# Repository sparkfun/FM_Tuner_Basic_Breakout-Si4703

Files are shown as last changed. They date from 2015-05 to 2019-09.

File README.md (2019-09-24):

SparkFun FM Tuner Basic Breakout - Si4703
========================================

SparkFun FM Tuner Basic Breakout - Si4703

[*SparkFun FM Tuner Basic Breakout - Si4703 (BOB-11083)*](https://www.sparkfun.com/products/11083)

This breakout for the Silicon Laboratories Si4703 FM tuner chip is a little more stripped down than our FM Tuner Evaluation Board. If your project already has an amp and just needs a full-featured FM tuner, this is the board for you. 

_Note: If you are using a different microcontroller that is 5V, you will need to connect to the [respective I2C pins](https://www.arduino.cc/en/reference/wire), and match the [logic levels](https://learn.sparkfun.com/tutorials/logic-levels). Make sure to add the [4-channel bi-directional logic level converter](https://www.sparkfun.com/products/12009) between SDIO, SCLK, RST, and GPIO2._

Repository Contents
-------------------

* **/Firmware** - Example code 
* **/Hardware** - Eagle design files (.brd, .sch)
* **/Libraries** - Libraries for use with the <PRODUCT NAME>
* **/Production** - Production panel files (.brd)

Documentation
--------------
* **[Library](https://github.com/sparkfun/SparkFun_Si4703_Arduino_Library)** - Arduino library for the Si4703.
* **[SparkFun Fritzing repo](https://github.com/sparkfun/Fritzing_Parts)** - Fritzing diagrams for SparkFun products.
* **[SparkFun 3D Model repo](https://github.com/sparkfun/3D_Models)** - 3D models of SparkFun products. 

License Information
-------------------
This product is _**open source**_! 

The **hardware** is released under [Creative Commons ShareAlike 4.0 International](https://creativecommons.org/licenses/by-sa/4.0/).

The **code** is beerware; if you see me (or any other SparkFun employee) at the local, and you've found our code helpful, please buy us a round!

Please use, reuse, and modify these files as you see fit. Please maintain attribution to SparkFun Electronics and release anything derivative under the same license.

Distributed as-is; no warranty is given.

- Your friends at SparkFun.

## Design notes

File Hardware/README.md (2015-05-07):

SparkFun <PRODUCT NAME> Design Files
=====================================

The .sch and .brd files hare are Eagle CAD schematic and PCB design files from SparkFun Electronics.
A freeware version of Eagle can be found [here](http://www.cadsoftusa.com/download-eagle/freeware/). 

License
---------
This product is open source! 
The hardware is released under [Creative Commons ShareAlike 4.0 International](https://creativecommons.org/licenses/by-sa/4.0/).

Please use, reuse, and modify these files as you see fit. Please maintain attribution to SparkFun Electronics and release anything derivative under the same license.

Distributed as-is; no warranty is given.

- Your friends at SparkFun.

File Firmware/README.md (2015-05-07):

SparkFun Si4703 Firmware
===================================

* **SparkFunSi4703Demo** - Arduino demo sketch. No library required.

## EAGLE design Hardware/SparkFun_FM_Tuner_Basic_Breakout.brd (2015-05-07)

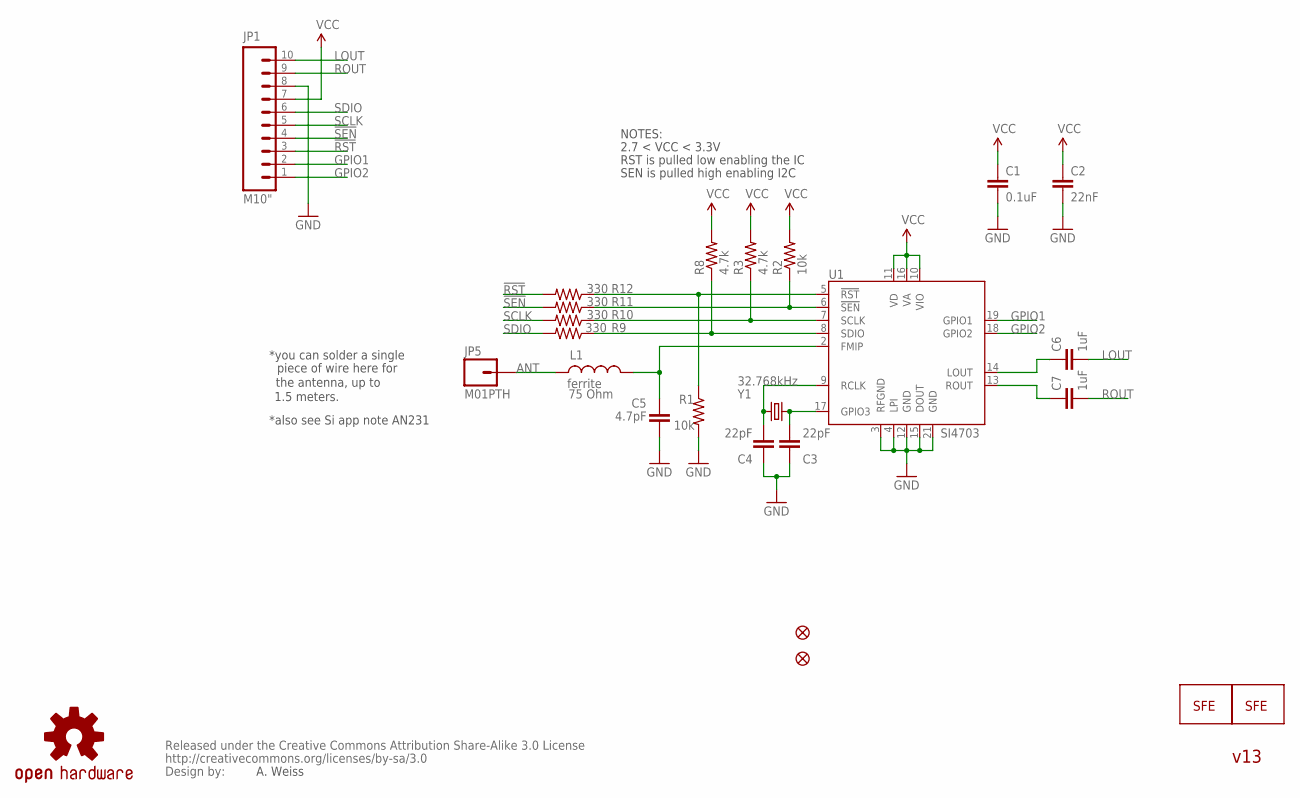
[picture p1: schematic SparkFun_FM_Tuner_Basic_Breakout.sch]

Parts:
C1: 0.1uF; 0402-CAP
C2: 22nF; 0402-CAP
C3, C4: 22pF; 0402-CAP
C5: 4.7pF; 0402-CAP
C6, C7: 1uF; 0402-CAP
JP1: M10"; 1X10
JP2: LOGO-SFENW2; SFE-NEW-WEB
JP3: LOGO-SFESK; SFE-LOGO-FLAME
JP4, JP6: FIDUCIALUFIDUCIAL; MICRO-FIDUCIAL
JP5: M01PTH; 1X01
L1: ferrite; C0402
R1, R2: 10k; 0402-RES
R3, R8: 4.7k; 0402-RES
R9, R10, R11, R12: 330; 0402-RES
U1: SI4703; SPARKFUN_SI470X
U$1: CREATIVE_COMMONS
U$3: OSHW-LOGOS; OSHW-LOGO-S
Y1: 32.768kHz; CRYSTAL-32KHZ-SMD

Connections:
3.3V: C1.1, C2.1, JP1.7, R2.2, R3.2, R8.2, U1.10 (VIO), U1.11 (VD), U1.16 (VA)
!RST: JP1.3, R12.2
!RST-L: R1.1, R12.1, U1.5 (!RST)
!SEN: JP1.4, R11.2
!SEN-L: R2.1, R11.1, U1.6 (!SEN)
ANT: JP5.1, L1.1
GND: C1.2, C2.2, C3.1, C4.1, C5.2, JP1.8, R1.2, U1.3 (RFGND), U1.4 (LPI), U1.12 (GND), U1.15 (DOUT), U1.21 (GND)
GPIO1: JP1.2, U1.19 (GPIO1)
GPIO2: JP1.1, U1.18 (GPIO2)
LOUT: C6.2, JP1.10
unnamed: C4.2, U1.9 (RCLK), Y1.X2 (2)
unnamed: C3.2, U1.17 (GPIO3), Y1.X1 (1)
unnamed: C5.1, L1.2, U1.2 (FMIP)
unnamed: C6.1, U1.14 (LOUT)
unnamed: C7.1, U1.13 (ROUT)
ROUT: C7.2, JP1.9
SCLK: JP1.5, R10.2
SCLK-L: R3.1, R10.1, U1.7 (SCLK)
SDIO: JP1.6, R9.2
SDIO-L: R8.1, R9.1, U1.8 (SDIO)

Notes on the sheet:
SEN is pulled high enabling I2C
RST is pulled low enabling the IC
A. Weiss
2.7 < VCC < 3.3V
NOTES:
*you can solder a single
piece of wire here for
the antenna, up to
1.5 meters.
*also see Si app note AN231
v13

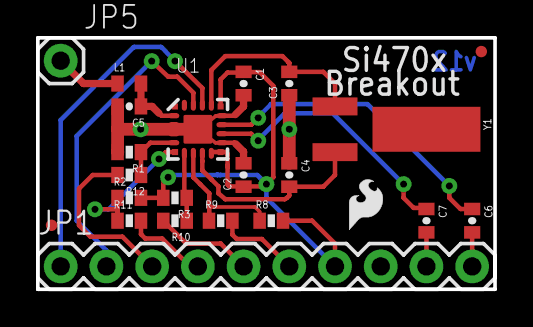
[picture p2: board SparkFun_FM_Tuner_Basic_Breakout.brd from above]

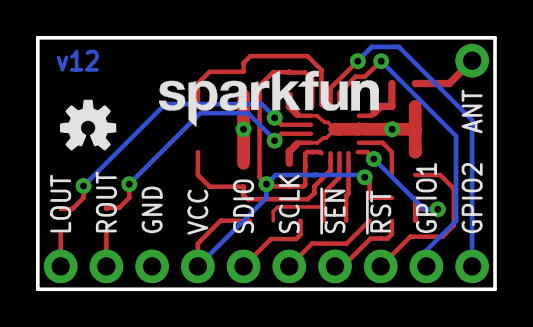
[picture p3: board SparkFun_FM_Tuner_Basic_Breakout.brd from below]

Board: 2 copper layers, 25.4 x 14.0 mm, 26 parts (2 on the bottom side), 20 nets.

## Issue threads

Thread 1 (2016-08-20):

No need to wait for data after Wire.requestFrom()

Koepel, 2016-08-20:
In one place in SparkFunSi4703Demo.ino, there is a while-loop after the Wire.requestFrom() call. That while-loop is not needed.

When the Wire.requestFrom() function returns, the I2C transaction has completely finished and the received data is in the receive buffer in the Wire library. The Wire.read() only reads data from that buffer.

When there was a I2C bus error or I2C collision, there would be less bytes received, and that while-loop would halt the sketch.

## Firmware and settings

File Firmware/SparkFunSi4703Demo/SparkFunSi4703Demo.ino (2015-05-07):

/*
 1-6-2011
 Spark Fun Electronics 2011
 Nathan Seidle
 
 This code is public domain but you buy me a beer if you use this and we meet someday (Beerware license).
 
 To use this code, connect the following 5 wires:
 Arduino : Si470x board
 3.3V : VCC
 GND : GND
 A5 : SCLK
 A4 : SDIO
 D2 : RST
 A0 : Trimpot (optional)
 
 Look for serial output at 57600bps.
 
 The Si4703 ACKs the first byte, and NACKs the 2nd byte of a read.
 
 1/18 - after much hacking, I suggest NEVER write to a register without first reading the contents of a chip.
 ie, don't updateRegisters without first readRegisters.
 
 If anyone manages to get this datasheet downloaded
 http://wenku.baidu.com/view/d6f0e6ee5ef7ba0d4a733b61.html
 Please let us know. It seem to be the latest version of the programming guide. It had a change on page 12 (write 0x8100 to 0x07)
 that allowed me to get the chip working..
 
 Also, if you happen to find "AN243: Using RDS/RBDS with the Si4701/03", please share. I love it when companies refer to
 documents that don't exist.
 
 1/20 - Picking up FM stations from a plane flying over Portugal! Sweet! 93.9MHz sounds a little soft for my tastes,s but
 it's in Porteguese.
 
 ToDo:
 Display current status (from 0x0A) - done 1/20/11
 Add RDS decoding - works, sort of
 Volume Up/Down - done 1/20/11
 Mute toggle - done 1/20/11
 Tune Up/Down - done 1/20/11
 Read current channel (0xB0) - done 1/20/11
 Setup for Europe - done 1/20/11
 Seek up/down - done 1/25/11
 
 The Si4703 breakout does work with line out into a stereo or other amplifier. Be sure to test with different length 3.5mm
 cables. Too short of a cable may degrade reception.
 */

#include <Wire.h>

int STATUS_LED = 13;
int resetPin = 2;
int SDIO = A4; //SDA/A4 on Arduino
int SCLK = A5; //SCL/A5 on Arduino
char printBuffer[50];
uint16_t si4703_registers[16]; //There are 16 registers, each 16 bits large

#define FAIL  0
#define SUCCESS  1

#define SI4703 0x10 //0b._001.0000 = I2C address of Si4703 - note that the Wire function assumes non-left-shifted I2C address, not 0b.0010.000W
#define I2C_FAIL_MAX  10 //This is the number of attempts we will try to contact the device before erroring out

//#define IN_EUROPE //Use this define to setup European FM reception. I wuz there for a day during testing (TEI 2011).

#define SEEK_DOWN  0 //Direction used for seeking. Default is down
#define SEEK_UP  1

//Define the register names
#define DEVICEID 0x00
#define CHIPID  0x01
#define POWERCFG  0x02
#define CHANNEL  0x03
#define SYSCONFIG1  0x04
#define SYSCONFIG2  0x05
#define STATUSRSSI  0x0A
#define READCHAN  0x0B
#define RDSA  0x0C
#define RDSB  0x0D
#define RDSC  0x0E
#define RDSD  0x0F

//Register 0x02 - POWERCFG
#define SMUTE  15
#define DMUTE  14
#define SKMODE  10
#define SEEKUP  9
#define SEEK  8

//Register 0x03 - CHANNEL
#define TUNE  15

//Register 0x04 - SYSCONFIG1
#define RDS  12
#define DE  11

//Register 0x05 - SYSCONFIG2
#define SPACE1  5
#define SPACE0  4

//Register 0x0A - STATUSRSSI
#define RDSR  15
#define STC  14
#define SFBL  13
#define AFCRL  12
#define RDSS  11
#define STEREO  8

void setup() {                
  pinMode(13, OUTPUT);
  pinMode(A0, INPUT); //Optional trimpot for analog station control

  Serial.begin(57600);
  Serial.println();

  si4703_init(); //Init the Si4703 - we need to toggle SDIO before Wire.begin takes over.

}

void loop() {
  char option;
  char vol = 15;
  int currentChannel = 973; //Default the unit to a known good local radio station

  gotoChannel(currentChannel);

  while(1) {
    Serial.println();
    Serial.println("Si4703 Configuration");

    currentChannel = readChannel();
    sprintf(printBuffer, "Current station: %02d.%01dMHz", currentChannel / 10, currentChannel % 10);
    Serial.println(printBuffer);

#ifdef IN_EUROPE
    Serial.println("Configured for European Radio");
#endif

    Serial.println("1) Tune to 97.3");
    Serial.println("2) Mute On/Off");
    Serial.println("3) Display status");
    Serial.println("4) Seek up");
    Serial.println("5) Seek down");
    Serial.println("6) Poll for RDS");
    Serial.println("r) Print registers");
    Serial.println("8) Turn GPIO1 High");
    Serial.println("9) Turn GPIO1 Low");
    Serial.println("v) Volume");
    Serial.println("w) Tune up");
    Serial.println("s) Tune down");
    Serial.print(": ");

    while (!Serial.available());
    option = Serial.read();

    if(option == '1')  {
      Serial.println("Tune to 97.3");
      currentChannel = 973;
      //currentChannel = 1023;
      gotoChannel(currentChannel);
    }
    else if(option == '2') {
      Serial.println("Mute toggle");
      si4703_readRegisters();
      si4703_registers[POWERCFG] ^= (1<<DMUTE); //Toggle Mute bit
      si4703_updateRegisters();
    }
    else if(option == '3') {
      si4703_readRegisters();

      Serial.println();
      Serial.println("Radio Status:");

      if(si4703_registers[STATUSRSSI] & (1<<RDSR)){
        Serial.print(" (RDS Available)");

        byte blockerrors = (si4703_registers[STATUSRSSI] & 0x0600) >> 9; //Mask in BLERA
        if(blockerrors == 0) Serial.print (" (No RDS errors)");
        if(blockerrors == 1) Serial.print (" (1-2 RDS errors)");
        if(blockerrors == 2) Serial.print (" (3-5 RDS errors)");
        if(blockerrors == 3) Serial.print (" (6+ RDS errors)");
      }
      else
        Serial.print(" (No RDS)");

      if(si4703_registers[STATUSRSSI] & (1<<STC)) Serial.print(" (Tune Complete)");
      if(si4703_registers[STATUSRSSI] & (1<<SFBL)) 
        Serial.print(" (Seek Fail)");
      else
        Serial.print(" (Seek Successful!)");
      if(si4703_registers[STATUSRSSI] & (1<<AFCRL)) Serial.print(" (AFC/Invalid Channel)");
      if(si4703_registers[STATUSRSSI] & (1<<RDSS)) Serial.print(" (RDS Synch)");

      if(si4703_registers[STATUSRSSI] & (1<<STEREO)) 
        Serial.print(" (Stereo!)");
      else
        Serial.print(" (Mono)");

      byte rssi = si4703_registers[STATUSRSSI] & 0x00FF; //Mask in RSSI
      Serial.print(" (RSSI=");
      Serial.print(rssi, DEC);
      Serial.println(" of 75)");
    }
    else if(option == '4') {
      seek(SEEK_UP);
    }
    else if(option == '5') {
      seek(SEEK_DOWN);
    }
    else if(option == '6') {
      Serial.println("Poll RDS - x to exit");
      while(1) {
        if(Serial.available() > 0)
          if(Serial.read() == 'x') break;

        si4703_readRegisters();
        if(si4703_registers[STATUSRSSI] & (1<<RDSR)){
          Serial.println("We have RDS!");
          byte Ah, Al, Bh, Bl, Ch, Cl, Dh, Dl;
          Ah = (si4703_registers[RDSA] & 0xFF00) >> 8;
          Al = (si4703_registers[RDSA] & 0x00FF);

          Bh = (si4703_registers[RDSB] & 0xFF00) >> 8;
          Bl = (si4703_registers[RDSB] & 0x00FF);

          Ch = (si4703_registers[RDSC] & 0xFF00) >> 8;
          Cl = (si4703_registers[RDSC] & 0x00FF);

          Dh = (si4703_registers[RDSD] & 0xFF00) >> 8;
          Dl = (si4703_registers[RDSD] & 0x00FF);

          Serial.print("RDS: ");
          Serial.print(Ah);
          Serial.print(Al);
          Serial.print(Bh);
          Serial.print(Bl);
          Serial.print(Ch);
          Serial.print(Cl);
          Serial.print(Dh);
          Serial.print(Dl);
          Serial.println(" !");

          delay(40); //Wait for the RDS bit to clear
        }
        else {
          Serial.println("No RDS");
          delay(30); //From AN230, using the polling method 40ms should be sufficient amount of time between checks
        }
        //delay(500);
      }
    }
    else if(option == '8') {
      Serial.println("GPIO1 High");
      si4703_registers[SYSCONFIG1] |= (1<<1) | (1<<0);
      si4703_updateRegisters();
    }
    else if(option == '9') {
      Serial.println("GPIO1 Low");
      si4703_registers[SYSCONFIG1] &= ~(1<<0);
      si4703_updateRegisters();
    }
    else if(option == 'r') {
      Serial.println("Print registers");
      si4703_printRegisters();
    }
    else if(option == 't') {
      Serial.println("Trim pot tuning");
      while(1) {
        if(Serial.available())
          if(Serial.read() == 'x') break;

        int trimpot = 0;
        for(int x = 0 ; x < 16 ; x++)
          trimpot += analogRead(A0);
        trimpot /= 16; //Take average of trimpot reading

        Serial.print("Trim: ");
        Serial.print(trimpot);
        trimpot = map(trimpot, 0, 1023, 875, 1079); //Convert the trimpot value to a valid station
        Serial.print(" station: ");
        Serial.println(trimpot);
        if(trimpot != currentChannel) {
          currentChannel = trimpot;
          gotoChannel(currentChannel);
        }

        delay(100);
      }
    }
    else if(option == 'v') {

      byte current_vol;

      Serial.println();
      Serial.println("Volume:");
      Serial.println("+) Up");
      Serial.println("-) Down");
      Serial.println("x) Exit");
      while(1){
        if(Serial.available()){
          option = Serial.read();
          if(option == '+') {
            si4703_readRegisters(); //Read the current register set
            current_vol = si4703_registers[SYSCONFIG2] & 0x000F; //Read the current volume level
            if(current_vol < 16) current_vol++; //Limit max volume to 0x000F
            si4703_registers[SYSCONFIG2] &= 0xFFF0; //Clear volume bits
            si4703_registers[SYSCONFIG2] |= current_vol; //Set new volume
            si4703_updateRegisters(); //Update
            Serial.print("Volume: ");
            Serial.println(current_vol, DEC);
          }
          if(option == '-') {
            si4703_readRegisters(); //Read the current register set
            current_vol = si4703_registers[SYSCONFIG2] & 0x000F; //Read the current volume level
            if(current_vol > 0) current_vol--; //You can't go lower than zero
            si4703_registers[SYSCONFIG2] &= 0xFFF0; //Clear volume bits
            si4703_registers[SYSCONFIG2] |= current_vol; //Set new volume
            si4703_updateRegisters(); //Update
            Serial.print("Volume: ");
            Serial.println(current_vol, DEC);
          }
          else if(option == 'x') break;
        }
      }
    }

    else if(option == 'w') {
      currentChannel = readChannel();
#ifdef IN_EUROPE
      currentChannel += 1; //Increase channel by 100kHz
#else
      currentChannel += 2; //Increase channel by 200kHz
#endif
      gotoChannel(currentChannel);
    }
    else if(option == 's') {
      currentChannel = readChannel();
#ifdef IN_EUROPE
      currentChannel -= 1; //Decreage channel by 100kHz
#else
      currentChannel -= 2; //Decrease channel by 200kHz
#endif
      gotoChannel(currentChannel);
    }
    else {
      Serial.print("Choice = ");
      Serial.println(option);
    }
  }
}

//Given a channel, tune to it
//Channel is in MHz, so 973 will tune to 97.3MHz
//Note: gotoChannel will go to illegal channels (ie, greater than 110MHz)
//It's left to the user to limit these if necessary
//Actually, during testing the Si4703 seems to be internally limiting it at 87.5. Neat.
void gotoChannel(int newChannel){
  //Freq(MHz) = 0.200(in USA) * Channel + 87.5MHz
  //97.3 = 0.2 * Chan + 87.5
  //9.8 / 0.2 = 49
  newChannel *= 10; //973 * 10 = 9730
  newChannel -= 8750; //9730 - 8750 = 980

#ifdef IN_EUROPE
    newChannel /= 10; //980 / 10 = 98
#else
  newChannel /= 20; //980 / 20 = 49
#endif

  //These steps come from AN230 page 20 rev 0.5
  si4703_readRegisters();
  si4703_registers[CHANNEL] &= 0xFE00; //Clear out the channel bits
  si4703_registers[CHANNEL] |= newChannel; //Mask in the new channel
  si4703_registers[CHANNEL] |= (1<<TUNE); //Set the TUNE bit to start
  si4703_updateRegisters();

  //delay(60); //Wait 60ms - you can use or skip this delay

  //Poll to see if STC is set
  while(1) {
    si4703_readRegisters();
    if( (si4703_registers[STATUSRSSI] & (1<<STC)) != 0) break; //Tuning complete!
    Serial.println("Tuning");
  }

  si4703_readRegisters();
  si4703_registers[CHANNEL] &= ~(1<<TUNE); //Clear the tune after a tune has completed
  si4703_updateRegisters();

  //Wait for the si4703 to clear the STC as well
  while(1) {
    si4703_readRegisters();
    if( (si4703_registers[STATUSRSSI] & (1<<STC)) == 0) break; //Tuning complete!
    Serial.println("Waiting...");
  }
}

//Reads the current channel from READCHAN
//Returns a number like 973 for 97.3MHz
int readChannel(void) {
  si4703_readRegisters();
  int channel = si4703_registers[READCHAN] & 0x03FF; //Mask out everything but the lower 10 bits

#ifdef IN_EUROPE
  //Freq(MHz) = 0.100(in Europe) * Channel + 87.5MHz
  //X = 0.1 * Chan + 87.5
  channel *= 1; //98 * 1 = 98 - I know this line is silly, but it makes the code look uniform
#else
  //Freq(MHz) = 0.200(in USA) * Channel + 87.5MHz
  //X = 0.2 * Chan + 87.5
  channel *= 2; //49 * 2 = 98
#endif

  channel += 875; //98 + 875 = 973
  return(channel);
}

//Seeks out the next available station
//Returns the freq if it made it
//Returns zero if failed
byte seek(byte seekDirection){
  si4703_readRegisters();

  //Set seek mode wrap bit
  //si4703_registers[POWERCFG] |= (1<<SKMODE); //Allow wrap
  si4703_registers[POWERCFG] &= ~(1<<SKMODE); //Disallow wrap - if you disallow wrap, you may want to tune to 87.5 first

  if(seekDirection == SEEK_DOWN) si4703_registers[POWERCFG] &= ~(1<<SEEKUP); //Seek down is the default upon reset
  else si4703_registers[POWERCFG] |= 1<<SEEKUP; //Set the bit to seek up

  si4703_registers[POWERCFG] |= (1<<SEEK); //Start seek

  si4703_updateRegisters(); //Seeking will now start

  //Poll to see if STC is set
  while(1) {
    si4703_readRegisters();
    if((si4703_registers[STATUSRSSI] & (1<<STC)) != 0) break; //Tuning complete!

    Serial.print("Trying station:");
    Serial.println(readChannel());
  }

  si4703_readRegisters();
  int valueSFBL = si4703_registers[STATUSRSSI] & (1<<SFBL); //Store the value of SFBL
  si4703_registers[POWERCFG] &= ~(1<<SEEK); //Clear the seek bit after seek has completed
  si4703_updateRegisters();

  //Wait for the si4703 to clear the STC as well
  while(1) {
    si4703_readRegisters();
    if( (si4703_registers[STATUSRSSI] & (1<<STC)) == 0) break; //Tuning complete!
    Serial.println("Waiting...");
  }

  if(valueSFBL) { //The bit was set indicating we hit a band limit or failed to find a station
    Serial.println("Seek limit hit"); //Hit limit of band during seek
    return(FAIL);
  }

  Serial.println("Seek complete"); //Tuning complete!
  return(SUCCESS);
}

//To get the Si4703 inito 2-wire mode, SEN needs to be high and SDIO needs to be low after a reset
//The breakout board has SEN pulled high, but also has SDIO pulled high. Therefore, after a normal power up
//The Si4703 will be in an unknown state. RST must be controlled
void si4703_init(void) {
  Serial.println("Initializing I2C and Si4703");
  
  pinMode(resetPin, OUTPUT);
  pinMode(SDIO, OUTPUT); //SDIO is connected to A4 for I2C
  digitalWrite(SDIO, LOW); //A low SDIO indicates a 2-wire interface
  digitalWrite(resetPin, LOW); //Put Si4703 into reset
  delay(1); //Some delays while we allow pins to settle
  digitalWrite(resetPin, HIGH); //Bring Si4703 out of reset with SDIO set to low and SEN pulled high with on-board resistor
  delay(1); //Allow Si4703 to come out of reset

  Wire.begin(); //Now that the unit is reset and I2C inteface mode, we need to begin I2C

  si4703_readRegisters(); //Read the current register set
  //si4703_registers[0x07] = 0xBC04; //Enable the oscillator, from AN230 page 9, rev 0.5 (DOES NOT WORK, wtf Silicon Labs datasheet?)
  si4703_registers[0x07] = 0x8100; //Enable the oscillator, from AN230 page 9, rev 0.61 (works)
  si4703_updateRegisters(); //Update

  delay(500); //Wait for clock to settle - from AN230 page 9

  si4703_readRegisters(); //Read the current register set
  si4703_registers[POWERCFG] = 0x4001; //Enable the IC
  //  si4703_registers[POWERCFG] |= (1<<SMUTE) | (1<<DMUTE); //Disable Mute, disable softmute
  si4703_registers[SYSCONFIG1] |= (1<<RDS); //Enable RDS

#ifdef IN_EUROPE
    si4703_registers[SYSCONFIG1] |= (1<<DE); //50kHz Europe setup
  si4703_registers[SYSCONFIG2] |= (1<<SPACE0); //100kHz channel spacing for Europe
#else
  si4703_registers[SYSCONFIG2] &= ~(1<<SPACE1 | 1<<SPACE0) ; //Force 200kHz channel spacing for USA
#endif

  si4703_registers[SYSCONFIG2] &= 0xFFF0; //Clear volume bits
  si4703_registers[SYSCONFIG2] |= 0x0001; //Set volume to lowest
  si4703_updateRegisters(); //Update

  delay(110); //Max powerup time, from datasheet page 13
}

//Write the current 9 control registers (0x02 to 0x07) to the Si4703
//It's a little weird, you don't write an I2C addres
//The Si4703 assumes you are writing to 0x02 first, then increments
byte si4703_updateRegisters(void) {

  Wire.beginTransmission(SI4703);
  //A write command automatically begins with register 0x02 so no need to send a write-to address
  //First we send the 0x02 to 0x07 control registers
  //In general, we should not write to registers 0x08 and 0x09
  for(int regSpot = 0x02 ; regSpot < 0x08 ; regSpot++) {
    byte high_byte = si4703_registers[regSpot] >> 8;
    byte low_byte = si4703_registers[regSpot] & 0x00FF;

    Wire.write(high_byte); //Upper 8 bits
    Wire.write(low_byte); //Lower 8 bits
  }

  //End this transmission
  byte ack = Wire.endTransmission();
  if(ack != 0) { //We have a problem! 
    Serial.print("Write Fail:"); //No ACK!
    Serial.println(ack, DEC); //I2C error: 0 = success, 1 = data too long, 2 = rx NACK on address, 3 = rx NACK on data, 4 = other error
    return(FAIL);
  }

  return(SUCCESS);
}

//Read the entire register control set from 0x00 to 0x0F
void si4703_readRegisters(void){

  //Si4703 begins reading from register upper register of 0x0A and reads to 0x0F, then loops to 0x00.
  Wire.requestFrom(SI4703, 32); //We want to read the entire register set from 0x0A to 0x09 = 32 bytes.

  while(Wire.available() < 32) ; //Wait for 16 words/32 bytes to come back from slave I2C device
  //We may want some time-out error here

  //Remember, register 0x0A comes in first so we have to shuffle the array around a bit
  for(int x = 0x0A ; ; x++) { //Read in these 32 bytes
    if(x == 0x10) x = 0; //Loop back to zero
    si4703_registers[x] = Wire.read() << 8;
    si4703_registers[x] |= Wire.read();
    if(x == 0x09) break; //We're done!
  }
}

void si4703_printRegisters(void) {
  //Read back the registers
  si4703_readRegisters();

  //Print the response array for debugging
  for(int x = 0 ; x < 16 ; x++) {
    sprintf(printBuffer, "Reg 0x%02X = 0x%04X", x, si4703_registers[x]);
    Serial.println(printBuffer);
  }
}

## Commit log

2015-05-07 Initial file commit
    [SparkFun_FM_Tuner_Basic_Breakout.brd, SparkFun_FM_Tuner_Basic_Breakout.sch]
2015-05-07 Squashed 'Libraries/Arduino/' content from commit 9eac801
    git-subtree-dir: Libraries/Arduino
    git-subtree-split: 9eac801e8865f5b5235ab0d2657a47cae651a9bb

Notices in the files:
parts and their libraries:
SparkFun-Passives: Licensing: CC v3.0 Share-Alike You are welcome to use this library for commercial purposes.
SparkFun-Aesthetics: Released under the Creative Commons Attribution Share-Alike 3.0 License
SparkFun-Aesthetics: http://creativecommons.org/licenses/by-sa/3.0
